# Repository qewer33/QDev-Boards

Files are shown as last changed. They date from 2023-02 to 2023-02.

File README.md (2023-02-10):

# QDev Boards

QDev Boards is a series of development boards that are inexpensive, simple and easy to order and assemble for beginner hobbyists.

This repository currently only has one entry but I plan to add more as I design and protoype new boards.

I am still fairly new and inexperienced when it comes to electronics and PCB design so if you have any suggestions or critics, please send them my way.

## Series

QDev Tiny (ATtiny25/45/85-PU): https://github.com/qewer33/QDev-Boards/tree/main/QDevTiny

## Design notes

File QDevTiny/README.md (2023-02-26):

## QDev Tiny

| Property | Value |
| --- | --- |
| Revision | 1 |
| Microcontroller | ATtiny25/45/85-PU |
| ISP Connector | Yes |
| USB Support | Yes (software) |
| GPIO Count | 6 (1 passive) |

### Description

QDevTiny is a small board that is built around the Atmel ATTiny25/45/85 microcontroller. It has an 8 pin header, 6 of them being GPIO pins. It also includes an ISP programming header for easy use with Atmel programmers. The board has a USB Type-A male edge connector for power and USB programming. USB programming requires the Micronucleus bootloader (which provides software USB support for certain Atmel microcontrollers) to be flashed.

### Supported Microcontroller Chips

| Microcontroller | Flash | SRAM | EEPROM |
| --- | ----- | ---- | --- |
| ATtiny25 | 2KB | 128B | 128B |
| ATtiny45 | 4KB | 256B | 256B |
| ATtiny85 | 8KB | 512B | 512B |

### Setup Instructions

These instructions are for Linux. For other operating systems, the provided commands may be different.

1. To burn the Micronucleus bootloader, you need an Arduino UNO/Mega/Nano or an AVR ISP programmer. Open the `Examples > Arduino ISP` sketch in Arduino IDE, uncomment the line with `#define USE_OLD_STYLE_WIRING` and upload it to your Arduino board.

2. Open the Arduino IDE preferences and add the ATtiny Core library JSON link (http://drazzy.com/package_drazzy.com_index.json) to "Board Manager URLs" section. Wait for the Arduino IDE to process it and then install the ATtiny Core package from the Boards Manager.

3. Wire the QDev Tiny pins to the Arduino for programming.
    - 5V -> VCC
    - GND -> GND
    - 10 -> R/IO5
    - 11 -> IO0
    - 12 -> IO1
    - 13 -> IO2

4. Download the Micronucleus ATtiny85 binary from: https://raw.githubusercontent.com/micronucleus/micronucleus/master/firmware/releases/t85_default.hex

5. Open the terminal  in the folder you downloaded the Micronucleus binary in and run the following command. Replace `/dev/ttyUSB0` with the correct port if necessary.

```sh
sudo avrdude -c arduino -b 19200 -P /dev/ttyUSB0 -p t85 -U flash:w:t85_default.hex -U lfuse:w:0xF1:m -U hfuse:w:0xDD:m -U efuse:w:0xFE:m
```

Micronucleus should now be flashed. Disconnect the programming pins and plug your board into your computer. Check the output of the `lsusb` command. Your board should show up as `MCS Digistump DigiSpark`.

To upload a program to your board via USB, export your program via `Sketch > Export Compiled Binary`. Open the terminal in the build folder of your sketch and run the following command (change "your_program_name.hex" with the hex file of your program):

```sh
avrdude -c micronucleus -p t85 -x wait -V -U flash:w:your_program_name.hex
```

You can also download the Micronucleus CLI tool from https://github.com/micronucleus/micronucleus/releases/tag/v2.6 and use it to upload your programs:

```sh
micronucleus your_program_name.hex
```

You may need to press the reset button before uploading your program.

### Images

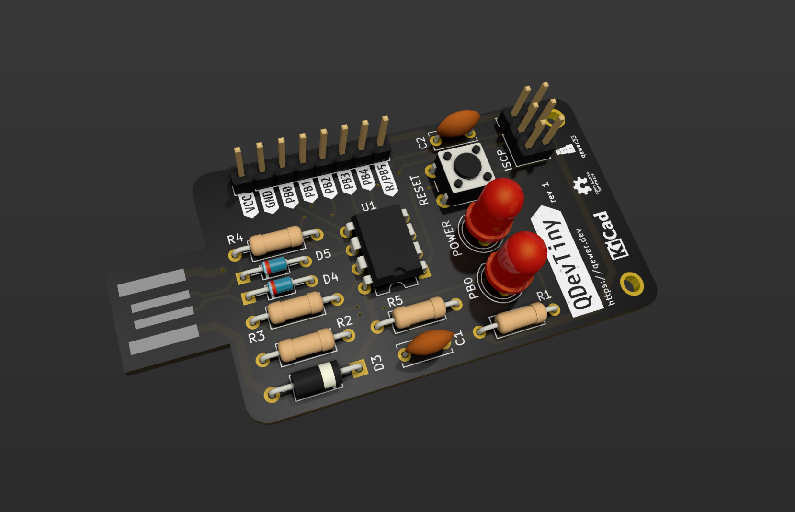
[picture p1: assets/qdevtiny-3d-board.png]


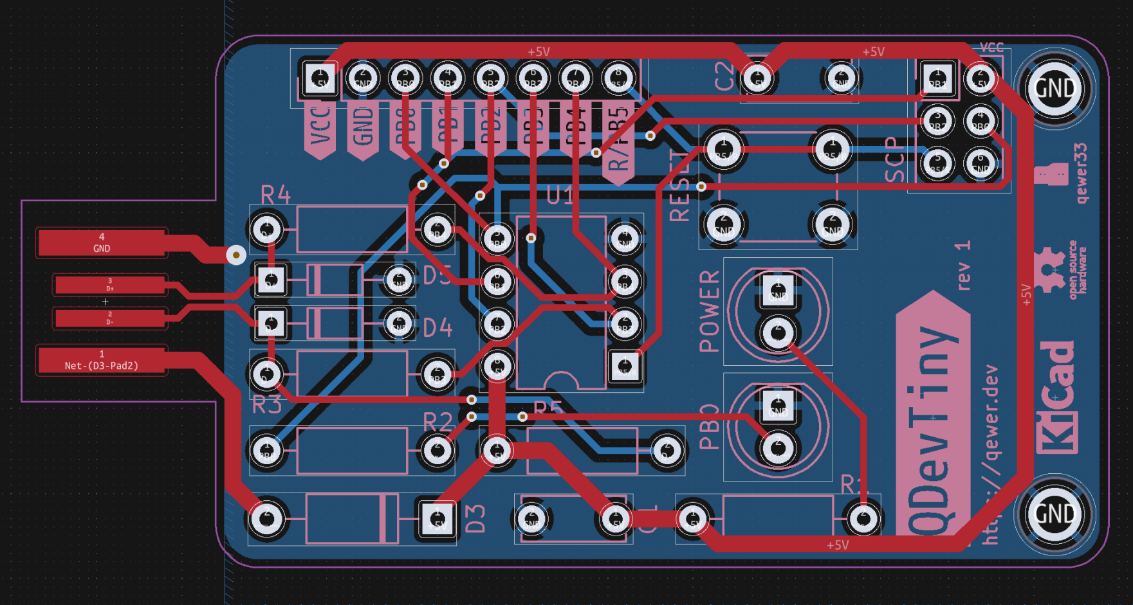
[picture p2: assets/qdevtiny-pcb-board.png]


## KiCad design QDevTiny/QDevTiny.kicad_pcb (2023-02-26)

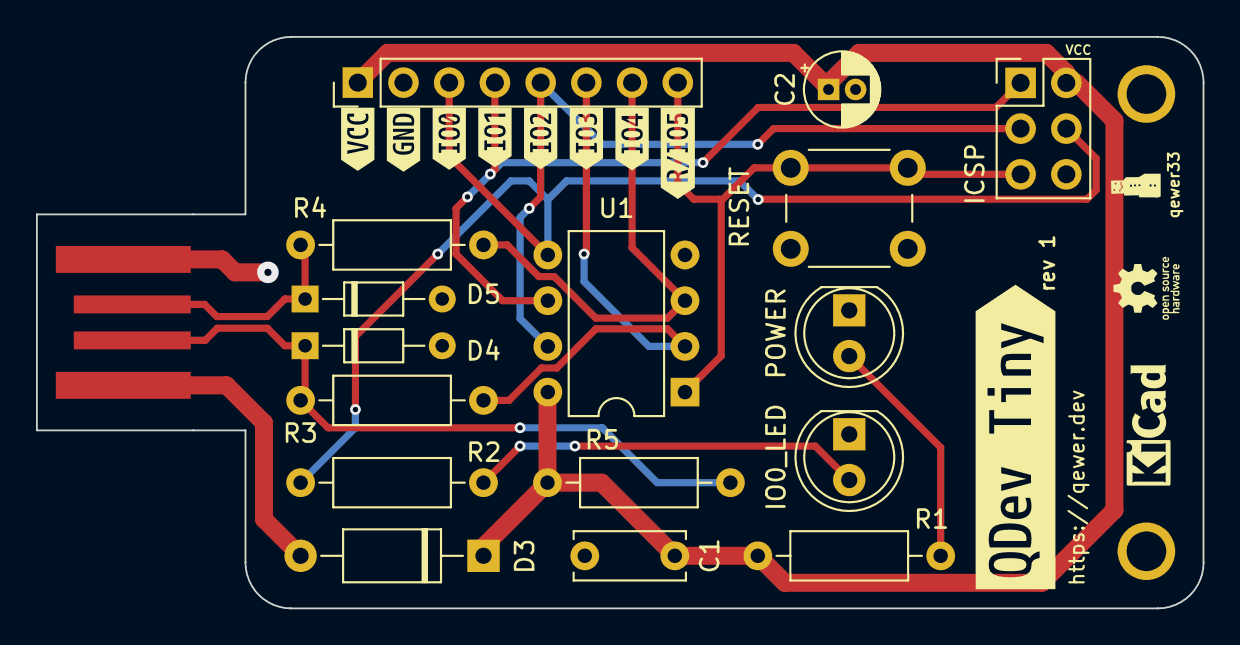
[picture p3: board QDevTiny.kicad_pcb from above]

Board: 2 copper layers, 64.8 x 31.8 mm, 26 parts (0 on the bottom side), 13 nets.

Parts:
C1: 0.1uF; C_Disc_D6.0mm_W2.5mm_P5.00mm
C2: 4.7uF; CP_Radial_D4.0mm_P1.50mm
D1: PWR_LED; LED_D5.0mm
D2: PB0_LED; LED_D5.0mm
D3: D; D_A-405_P10.16mm_Horizontal
D4, D5: 3.6V; D_DO-34_SOD68_P7.62mm_Horizontal
J1: USB_A; USB-A-PCB
J2: Header; PinHeader_1x08_P2.54mm_Vertical
J3: ICSP; PinHeader_2x03_P2.54mm_Vertical
R1, R2, R5: 1K; R_Axial_DIN0207_L6.3mm_D2.5mm_P10.16mm_Horizontal
R3, R4: 68R; R_Axial_DIN0207_L6.3mm_D2.5mm_P10.16mm_Horizontal
SW1: RESET_BTN; SW_PUSH_6mm
U1: ATtiny45-20P; DIP-8_W7.62mm
kibuzzard-63E3F582: G***; kibuzzard-63E3F582
kibuzzard-63E24FBF: G***; kibuzzard-63E24FBF
kibuzzard-63E51F9F: G***; kibuzzard-63E51F9F
kibuzzard-63E51F81: G***; kibuzzard-63E51F81
kibuzzard-63E51F95: G***; kibuzzard-63E51F95
kibuzzard-63E51FA9: G***; kibuzzard-63E51FA9
kibuzzard-63E51FAF: G***; kibuzzard-63E51FAF
kibuzzard-63E51FB7: G***; kibuzzard-63E51FB7
kibuzzard-63E270EC: G***; kibuzzard-63E270EC

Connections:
+5V: C1.1, C2.1, D3.1 (K), J2.1, J3.2 (VCC), R1.1, R5.1, U1.8 (VCC)
/D+: D5.1 (K), J1.3 (D+), R4.1
/D-: D4.1 (K), J1.2 (D-), R3.1, R5.2
GND: C1.2, C2.2, D1.1 (K), D2.1 (K), D4.2 (A), D5.2 (A), J1.4 (GND), J2.2, J3.6 (GND), SW1.2, U1.4 (GND)
unnamed: D1.2 (A), R1.2
unnamed: D2.2 (A), R2.2
unnamed: D3.2 (A), J1.1 (VBUS)
PB0: J2.3, J3.4 (MOSI), R2.1, U1.5 (AREF/PB0)
PB1: J2.4, J3.1 (MISO), U1.6 (PB1)
PB2: J2.5, J3.3 (SCK), U1.7 (PB2)
PB3: J2.6, R3.2, U1.2 (XTAL1/PB3)
PB4: J2.7, R4.2, U1.3 (XTAL2/PB4)
PB5/R: J2.8, J3.5 (~RST), SW1.1, U1.1 (~RESET/PB5)
